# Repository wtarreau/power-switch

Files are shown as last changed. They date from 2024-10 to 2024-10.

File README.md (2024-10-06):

power-switch
============

This project consists in controlling multiple power outputs for various
devices. Some USB-PD multi-port controllers only require minor modifications
to support being controlled and deliver power to individual devices.

The PCA9554D based board under boards/pca9554d-v3 controls 8 individual
USB-PD channels over I2C.

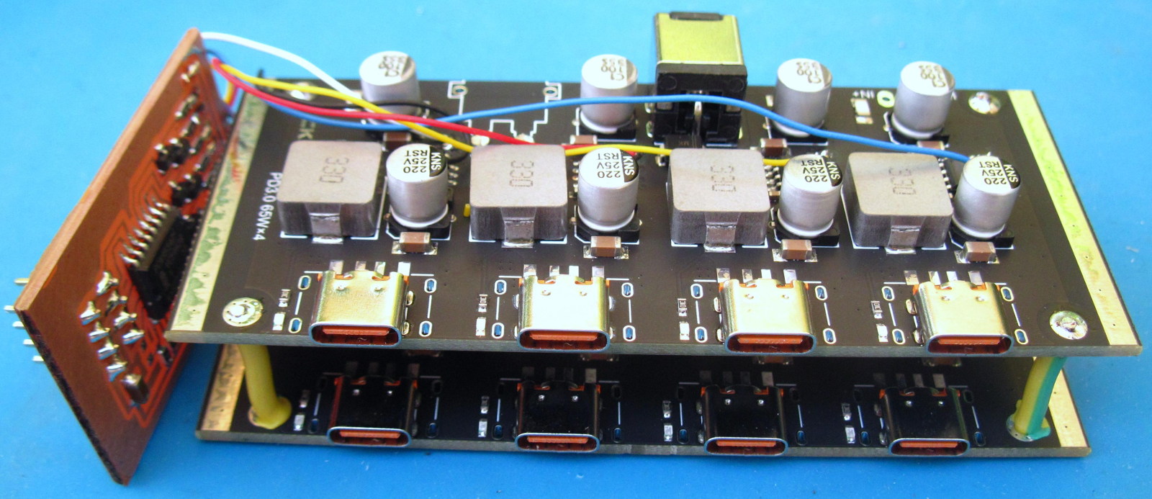
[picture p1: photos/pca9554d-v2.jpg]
PCA9554D-v2

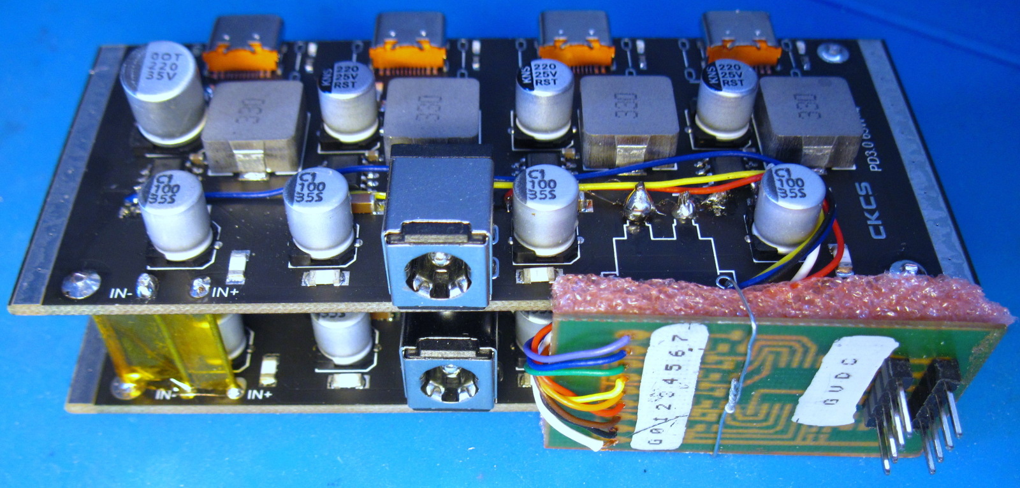
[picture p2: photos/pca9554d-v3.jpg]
PCA9554D-v3


The scripts/ directory contains a setup script, the "psw" script that's used to
list the ports states and change them, and a sample "psw.conf" config file to
map port numbers to GPIO numbers and descriptions.

Possible variations
===================

The project requires and open-drain output to control the CC1 line of
the USB-PD boards. Other devices such as 74HC596 or TPIC6B595 offer
open-drain variants of the ubiquitous 74HC595 that only requires 3
signals to control 8 lines (clock, data, register clock), and can
trivially be daisy-chained.

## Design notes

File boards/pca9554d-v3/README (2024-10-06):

2024-10-06 - v3

This is the 3rd version of the board using a PCA9554D (same pinout as
PCF8574D which should also work).

- open drain outputs using MOSFETs and 200 ohm resistors to protect
  against short-circuits

- GND placed left of output 0 instead of right of output 7

Files in this directory:
- bottom-copper = copper traces for components side (60 microns per pixel)
- bottom-cream = solder mask for components side (60 microns per pixel)
- pca9554d-3.sch = schematic (eagle 7.7 format)
- pca9554d-3.brd = board (eagle 7.7 format)
- schematic.png = rendered schematic

Board files were rendered at 60 microns per pixel (423.33 DPI) for laser
engraving or CNC etching but may also be printed for UV etching.

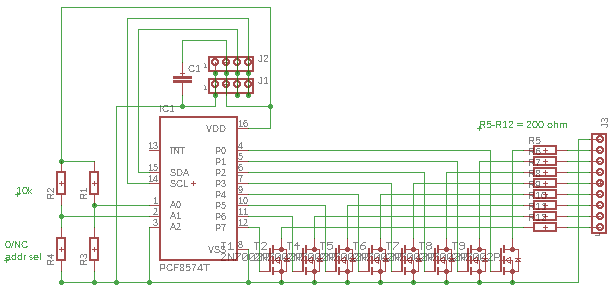
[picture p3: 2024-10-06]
boards/pca9554d-v3/schematic.png

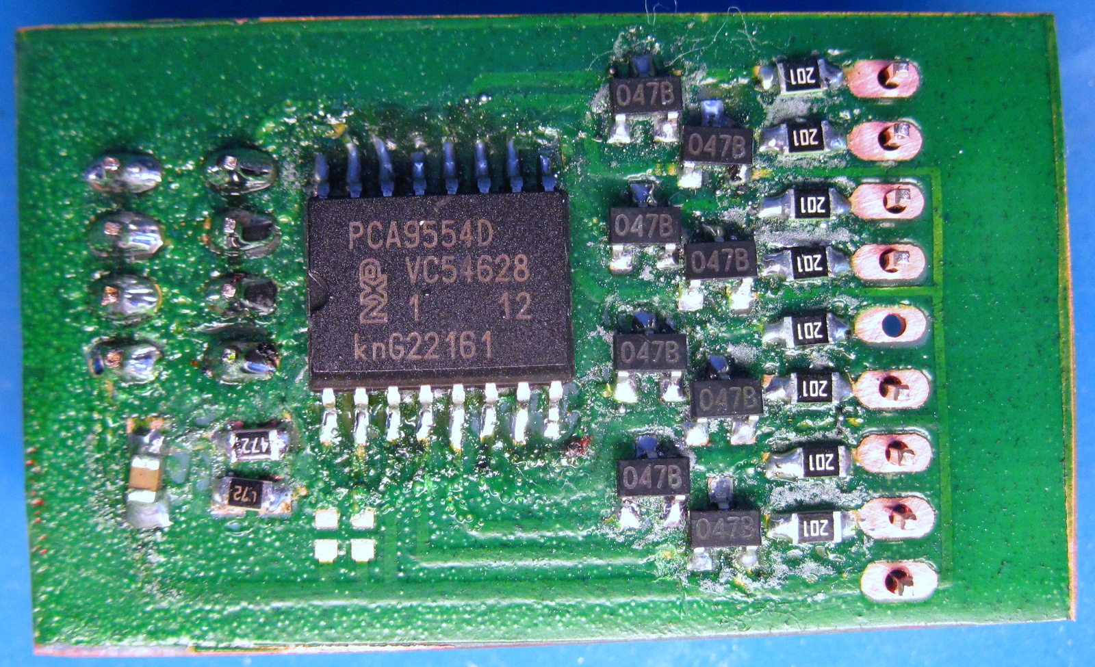
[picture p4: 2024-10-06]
photos/pca9554d-v3-bottom.jpg

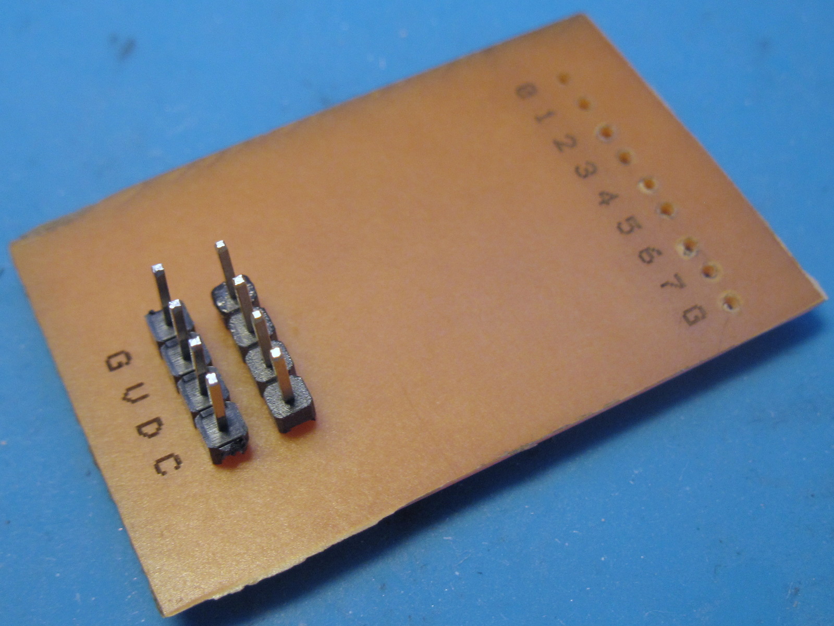
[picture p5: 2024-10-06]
photos/pca9554d-v2-top.jpg

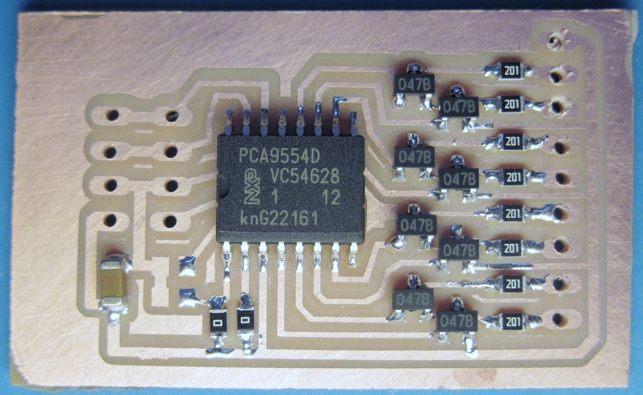
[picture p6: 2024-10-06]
photos/pca9554d-v2-bottom.jpg

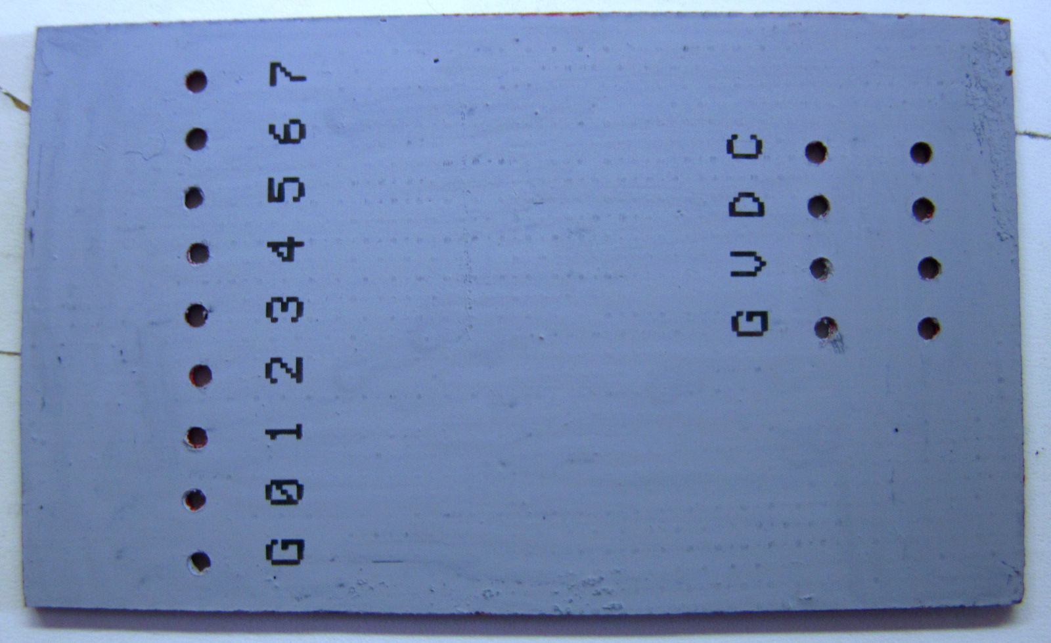
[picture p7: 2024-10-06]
photos/pca9554d-v3-top.jpg

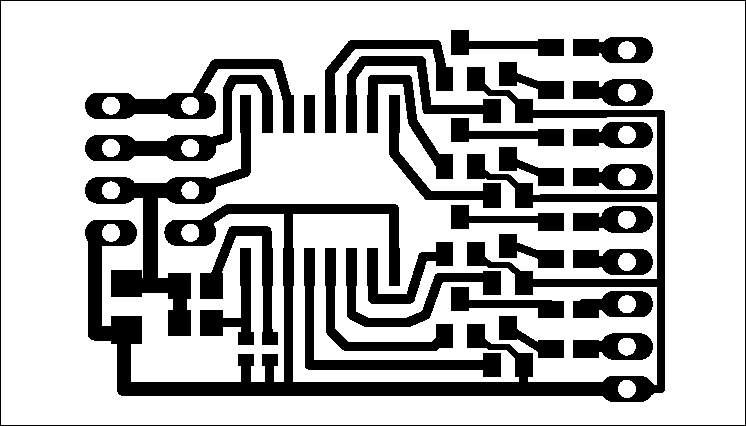
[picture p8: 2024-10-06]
boards/pca9554d-v3/bottom-copper.png

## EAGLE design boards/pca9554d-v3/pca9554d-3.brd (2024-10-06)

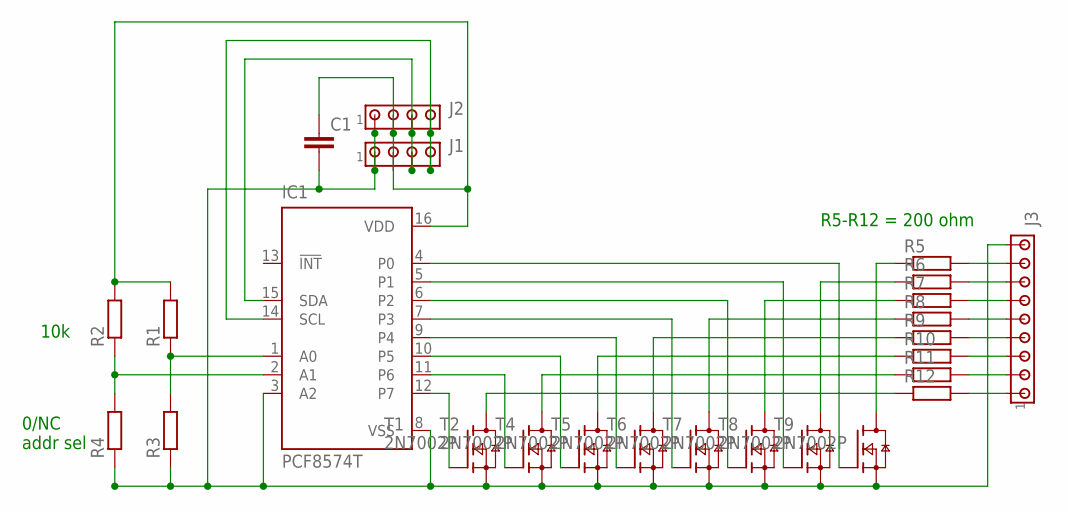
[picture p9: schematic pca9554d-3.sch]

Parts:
C1: C-EUC1206; C1206
IC1: PCF8574T; SO16W
J1, J2: MTA04-100; 10X04MTA
J3: MTA09-100; 10X09MTA
R1, R2: R-EU_R0805; R0805
R3, R4: R-EU_R0402; R0402
R5, R6, R7, R8, R9, R10, R11, R12: R-EU_R0805W; R0805W
T1, T2, T4, T5, T6, T7, T8, T9: 2N7002P; SOT23

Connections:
unnamed: C1.1, IC1.16 (VDD), J1.2, J2.2, R1.2, R2.2
unnamed: J3.8, R5.2
unnamed: IC1.15 (SDA), J1.3, J2.3
unnamed: IC1.14 (SCL), J1.4, J2.4
unnamed: IC1.1 (A0), R1.1, R3.2
unnamed: IC1.2 (A1), R2.1, R4.2
unnamed: IC1.12 (P7), T1.1 (G)
unnamed: J3.7, R6.2
unnamed: J3.6, R7.2
unnamed: J3.5, R8.2
unnamed: J3.4, R9.2
unnamed: J3.3, R10.2
unnamed: J3.2, R11.2
unnamed: J3.1, R12.2
unnamed: IC1.11 (P6), T2.1 (G)
unnamed: C1.2, IC1.3 (A2), IC1.8 (VSS), J1.1, J2.1, J3.9, R3.1, R4.1, T1.2 (S), T2.2 (S), T4.2 (S), T5.2 (S), T6.2 (S), T7.2 (S), T8.2 (S), T9.2 (S)
unnamed: IC1.10 (P5), T4.1 (G)
unnamed: IC1.9 (P4), T5.1 (G)
unnamed: IC1.7 (P3), T6.1 (G)
unnamed: IC1.6 (P2), T7.1 (G)
unnamed: IC1.5 (P1), T8.1 (G)
unnamed: IC1.4 (P0), T9.1 (G)
unnamed: R5.1, T9.3 (D)
unnamed: R6.1, T8.3 (D)
unnamed: R7.1, T7.3 (D)
unnamed: R8.1, T6.3 (D)
unnamed: R9.1, T5.3 (D)
unnamed: R10.1, T4.3 (D)
unnamed: R11.1, T2.3 (D)
unnamed: R12.1, T1.3 (D)

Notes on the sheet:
R5-R12 = 200 ohm
0/NC addr sel
10k

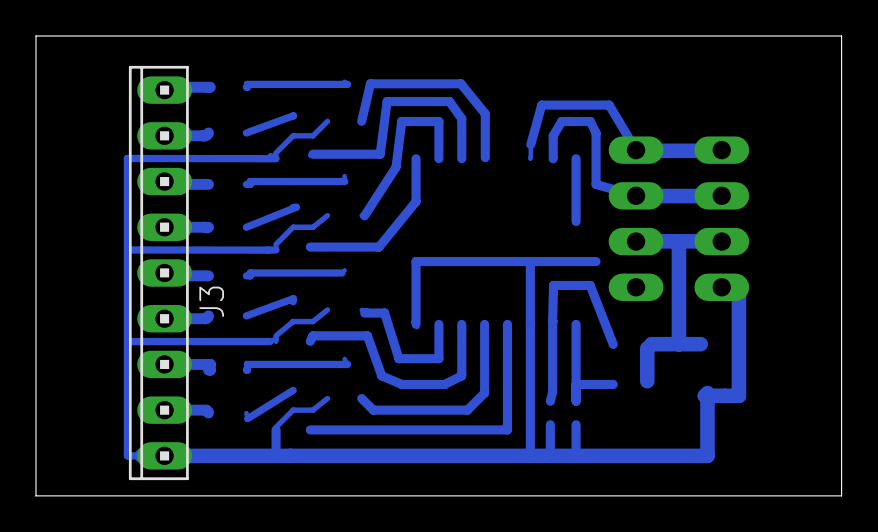
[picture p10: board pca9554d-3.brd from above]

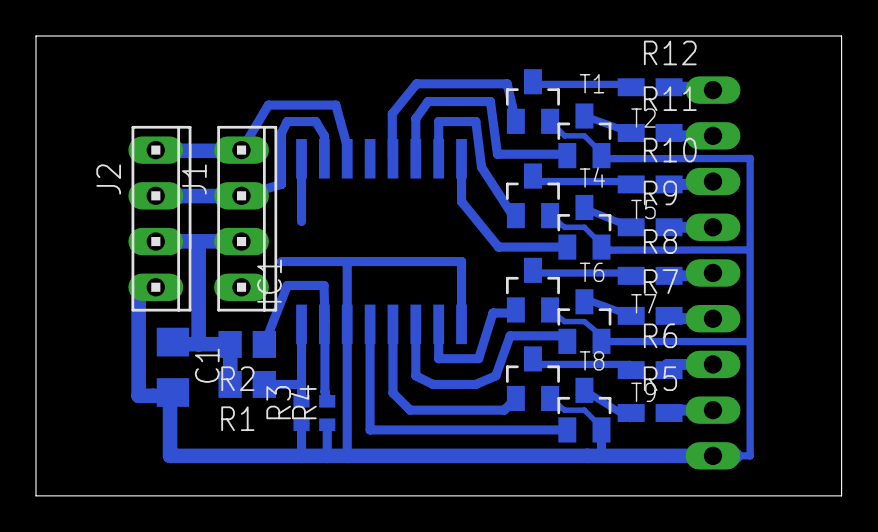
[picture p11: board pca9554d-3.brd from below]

Board: 2 copper layers, 44.8 x 25.5 mm, 25 parts (24 on the bottom side), 30 nets.

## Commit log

2024-10-06 Add pca9554d board (schematic, board, renderings and photos)
    This contains photos of both v2 and v3 board, though the schematic,
    renderings etc are only for v3.
    [pca9554d-3.brd, pca9554d-3.sch]
2024-10-06 Add scripts and sample config
    The psw script relies on psw.conf to find port numbers and GPIOs. The
    names are indicative and used only for listing.
